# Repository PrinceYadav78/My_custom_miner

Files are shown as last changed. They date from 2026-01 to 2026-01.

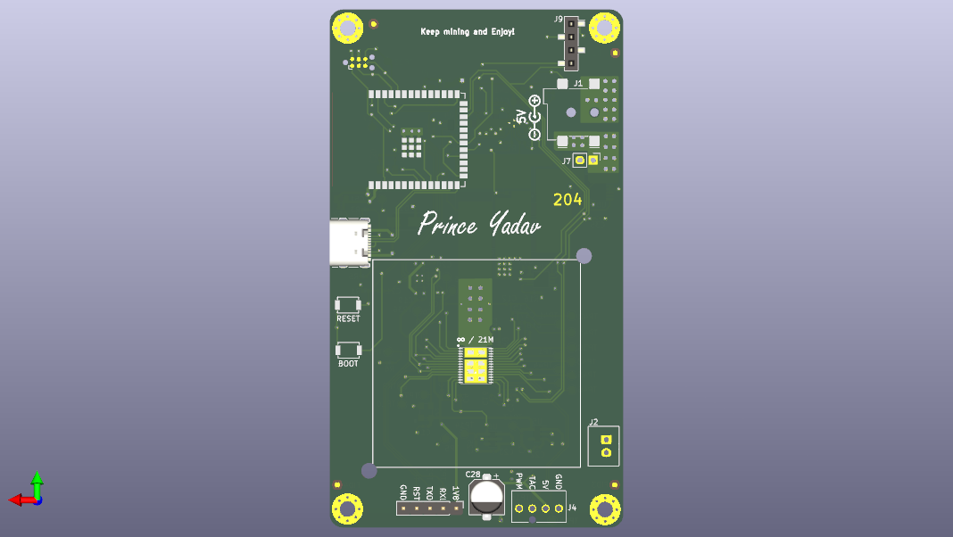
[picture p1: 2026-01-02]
img/2.png

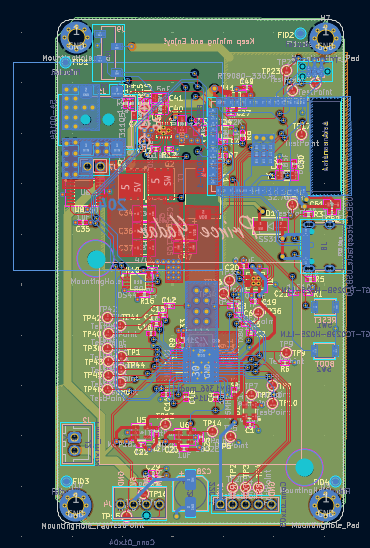
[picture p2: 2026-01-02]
img/Screenshot 2026-01-02 192543.png

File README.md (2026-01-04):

# Custom BM1366-Based Bitcoin Miner

## Overview
This project is a from-scratch design of a custom Bitcoin mining board built around the BM1366 ASIC.
The goal of this project was not to build a commercial miner, but to deeply understand how real mining
hardware is designed at the schematic and PCB level, including power delivery, grounding, routing,
and thermal considerations.

This is an educational hardware project focused on:
- High-current power delivery design
- Complex ASIC pinout handling
- Multi-rail voltage regulation
- PCB layout for power and thermal performance

## What This Board Does
- Provides regulated power rails required by the BM1366 ASIC
- Interfaces with the ASIC using SPI/control signals
- Routes extremely high current safely to the mining chip
- Is designed to be actively cooled using external heatsinks/fans
- Mines bitcoin with the firmware uploaded
The focus of this project is hardware design and manufacturability.

## Why I Built This
Most hobby electronics projects use microcontrollers or SoCs with forgiving power requirements.
Mining ASICs are the opposite — they are power-hungry, intolerant to mistakes, and layout-sensitive.
I wanted to push myself beyond typical PCB projects and learn how real mining hardware is built.

## PCB Image





## Cart




## Schematics







## BOM


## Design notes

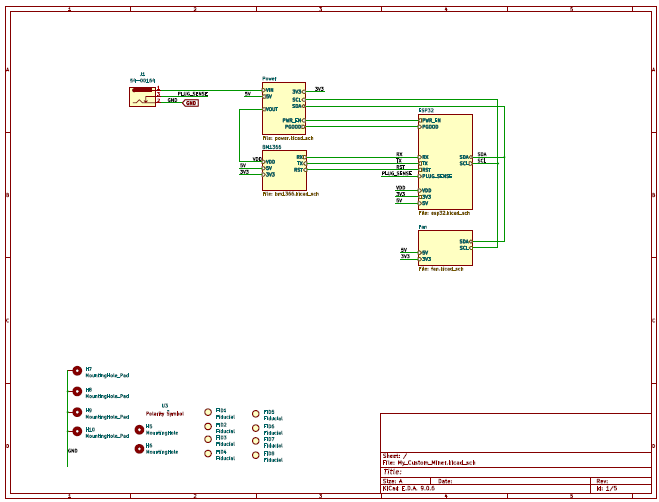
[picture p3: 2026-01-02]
img/Screenshot 2026-01-02 192621.png

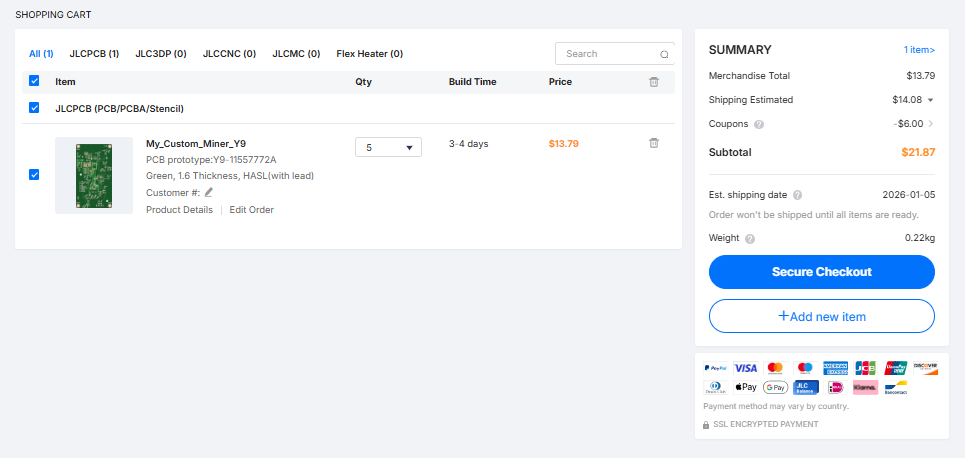
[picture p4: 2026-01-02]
img/Screenshot 2026-01-02 185541.png

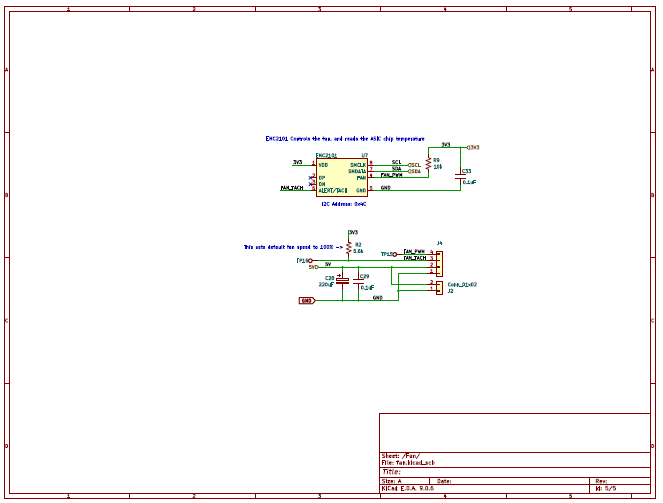
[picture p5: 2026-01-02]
img/Screenshot 2026-01-02 192647.png

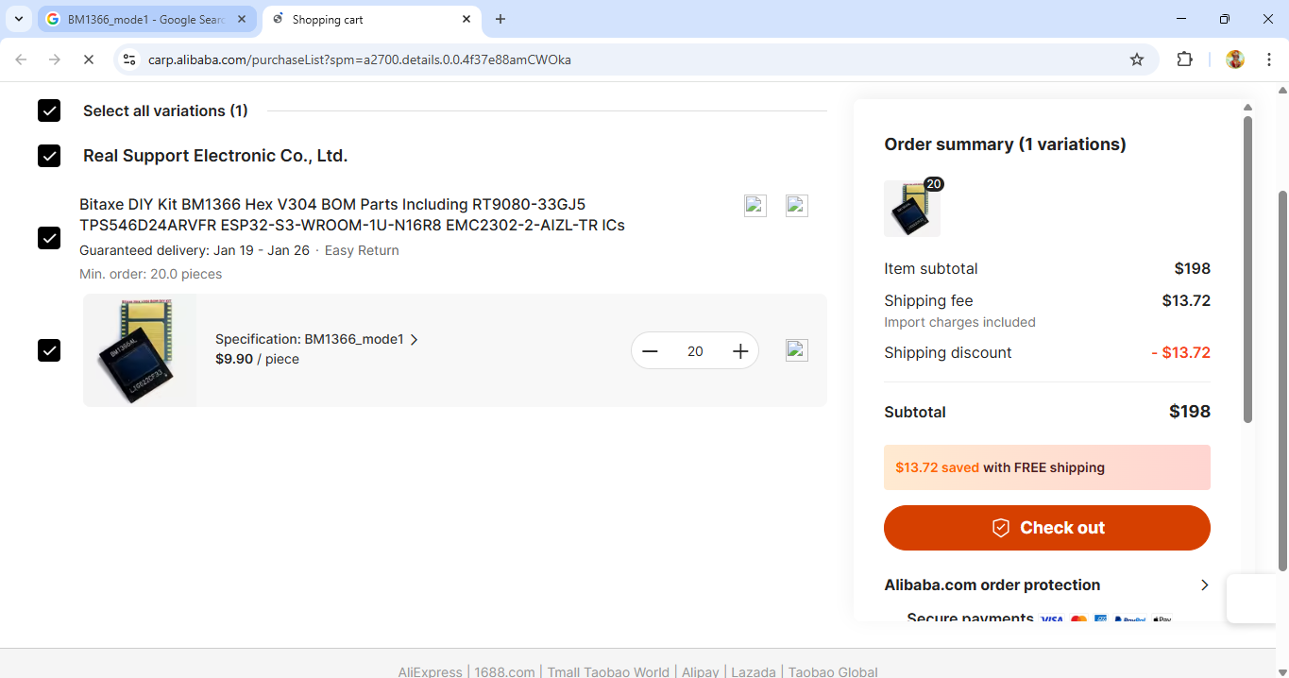
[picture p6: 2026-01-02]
img/Screenshot 2026-01-02 190240.png

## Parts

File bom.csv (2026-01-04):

Qty | Ref Des | Value | DK | PARTNO | DNP
9 | C1, C7, C9, C19, C20, C29, C33, C42, C52 | 0.1uF | 1292-1639-1-ND | 0402X104K100CT
23 | C2, C3, C4, C5, C6, C8, C10, C11, C12, C14, C15, C16, C17, C18, C21, C22, C23, C24, C25, C27, C35, C44, C49 | 1uF | 587-5514-1-ND | EMK105BJ105MV-F
1 | C13 | 330uF | 718-1028-1-ND | 293D337X9010E2TE3
1 | C28 | 220uF | 732-8422-1-ND | 865080345012
2 | C30, C31 | 6.8pF | 399-C0402C689C5GAC7867CT-ND | C0402C689C5GAC7867
3 | C34, C36, C37 | 47uF | 490-6539-1-ND | GRM32ER61C476KE15L
1 | C38 | 1uF | 1276-6471-1-ND | CL21B105KOFNNNG
1 | C39 | 3.3nF | 1276-1552-1-ND | CL05B332KB5NNNC
1 | C40 | 180pF | 311-1114-1-ND | CC0805JRNPO9BN181
1 | C41 | 1.5nF | 311-1128-1-ND | CC0805KRX7R9BB152
2 | C43, C51 | 10uF | 1276-1096-1-ND | CL21A106KOQNNNE
1 | C45 | 470pF | 1292-1580-1-ND | 0805B471K500CT
1 | C46 | 220uF | P16200CT-ND | 2R5TPE220MAFB
1 | C47 | 100uF | 445-6008-1-ND | C3216X5R0J107M160AB
1 | D1 | SS310 | SK310A-LTPMSCT-ND | SK310A-LTP
1 | J1 | 54-00164 | 839-54-00164CT-ND | 54-00164
1 | J2 | Conn_01x02 | 455-B2B-XH-A-ND | B2B-XH-A
1 | J4 | Conn_01x04 | WM4330-ND | 0470531000
1 | J8 | USB_C_Receptacle_USB2.0 | 2073-USB4105-GF-ACT-ND | USB4105-GF-A
1 | L1 | 150nH | 513-1568-1-ND | FP1005R1-R15-R
2 | Q1, Q2 | CSD17311Q5 | 296-27625-1-ND | CSD17311Q5
1 | Q4 | 2N7002K | 2N7002KWCT-ND | 2N7002KW
5 | R1, R4, R6, R7, R9 | 10k | 311-10KJRCT-ND | RC0402JR-0710KL
1 | R2 | 5.6k | 13-RC0402FR-135K6LCT-ND | RC0402FR-135K6L
2 | R3, R5 | 5.1k | RMCF0402JT5K10CT-ND | RMCF0402JT5K10
1 | R8 | 1M | 311-1.00MLRCT-ND | RC0402FR-071ML
1 | R10 | 3.83k | 311-3.83KLRCT-ND | RC0402FR-073K83L
1 | R12 | 4.12k | RMCF0402FT4K12CT-ND | RMCF0402FT4K12
1 | R13 | 1.33k | 311-1.33KLRCT-ND | RC0402FR-071K33L
1 | R14 | 4.99k | 311-4.99KLRCT-ND | RC0402FR-074K99L
1 | R15 | 3.32k | 311-3.32KLRCT-ND | RC0402FR-073K32L
1 | R16 | 80.6k | 311-80.6KLRCT-ND | RC0402FR-0780K6L
2 | SW1, SW2 | GT-TC029B-H025-L1N | 2449-CS1213AGF260CT-ND | CS1213AGF260
1 | U1 | 25MHz | 1908-O250-JO32-B-1V3-1-T1-LFCT-ND | O 25,0-JO32-B-1V3-1-T1-LF
1 | U2 | TXB0104RGYR | 296-21930-1-ND | TXB0104RGYR
1 | U5 | MCP1824T-1802E | MCP1824T-1802E/OTCT-ND | MCP1824T-1802E/OT
1 | U6 | MCP1824T-0802E | MCP1824T-0802E/OTCT-ND | MCP1824T-0802E/OT
1 | U7 | EMC2101 | EMC2101-R-ACZL-CT-ND | EMC2101-R-ACZL-TR
1 | U8 | INA260 | 296-45218-5-ND | INA260AIPW
1 | U9 | TPS40305 | 296-37445-1-ND | TPS40305DRCR
1 | U10 | DS4432U+ | DS4432U+-ND | DS4432U+
1 | U11 | RT9080-33GJ5 | 1028-1509-1-ND | RT9080-33GJ5
1 | U12 | ESP32-S3-WROOM-1 | 1965-ESP32-S3-WROOM-1-N16R8CT-ND | ESP32-S3-WROOM-1-N16R8
1 | U14 | BM1366_mode1
1 | Y1 | 32.768kHz | 728-1074-1-ND | SC32S-7PF20PPM
1 | J9 | Conn_01x04 | S5596-ND | NPTC041KFXC-RC

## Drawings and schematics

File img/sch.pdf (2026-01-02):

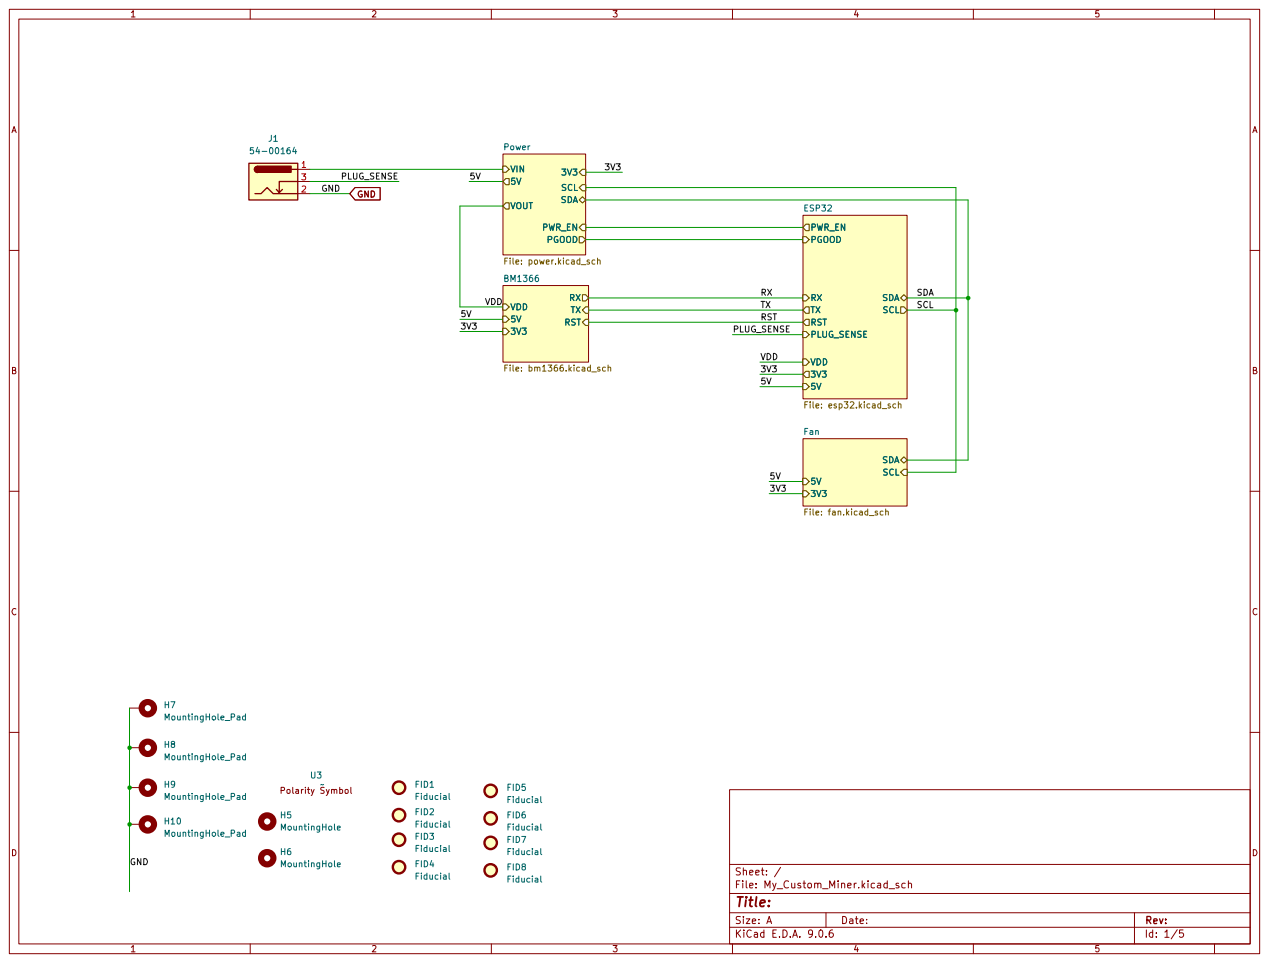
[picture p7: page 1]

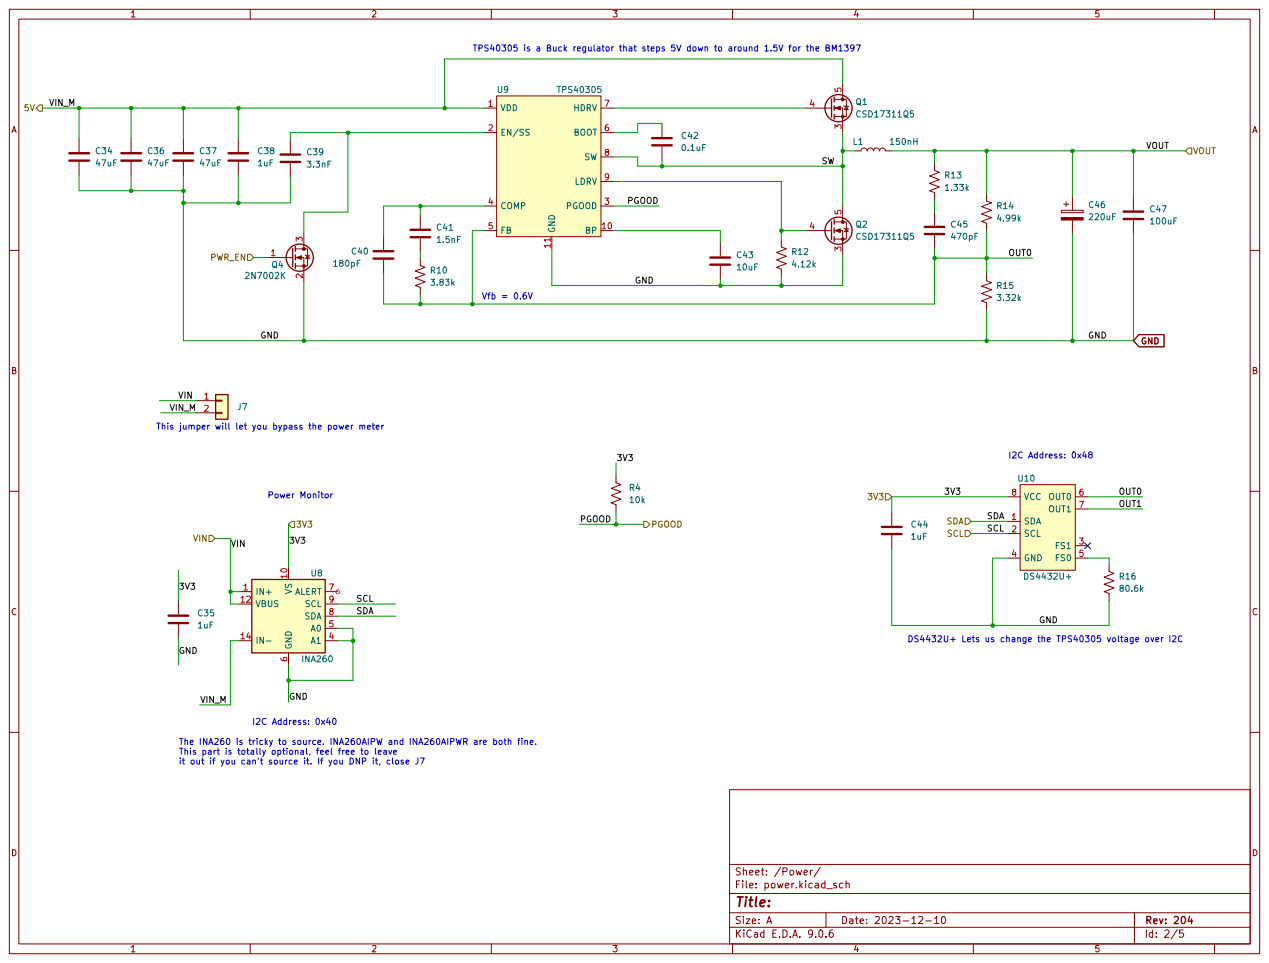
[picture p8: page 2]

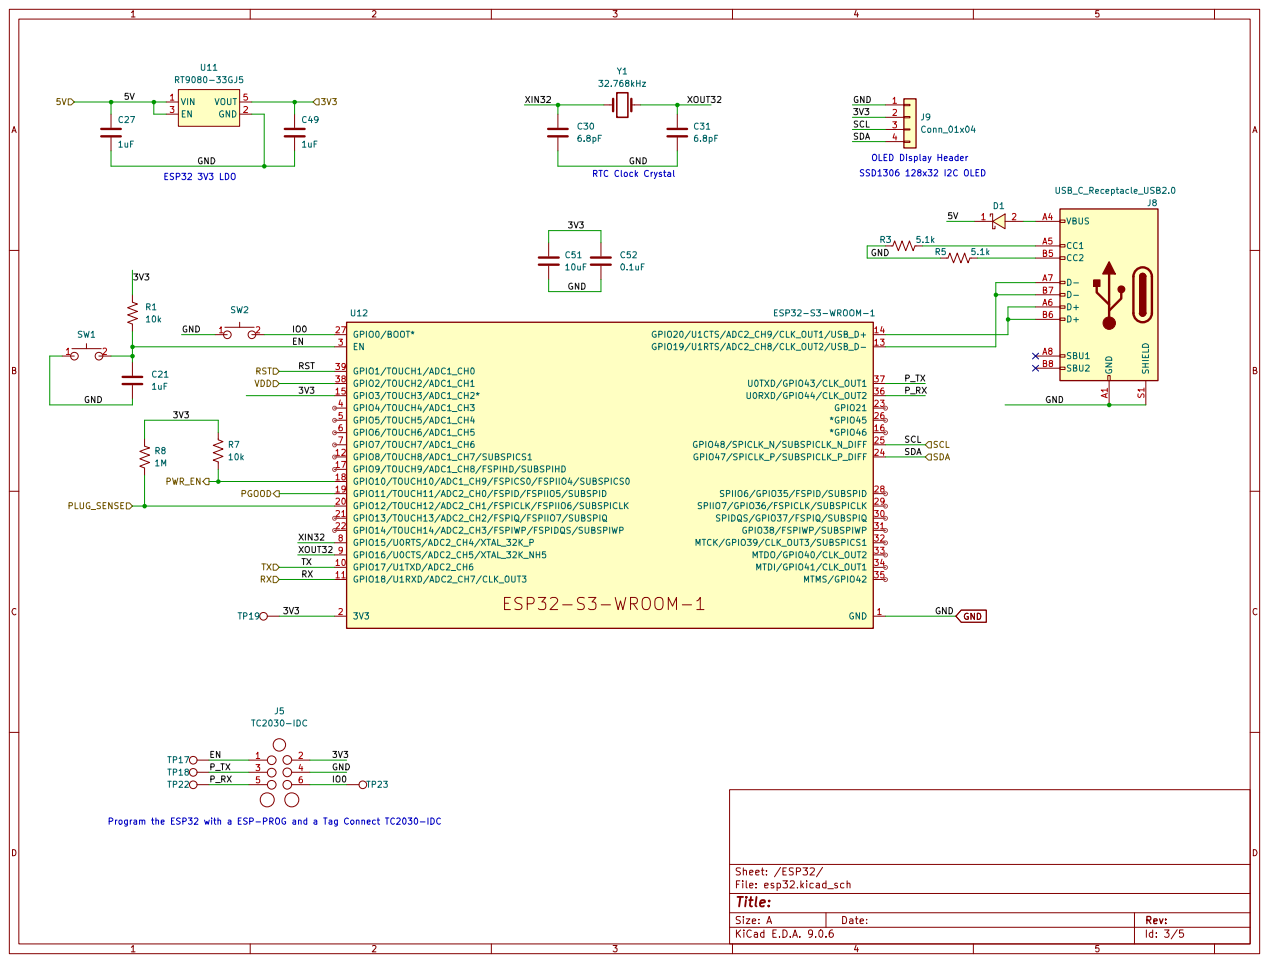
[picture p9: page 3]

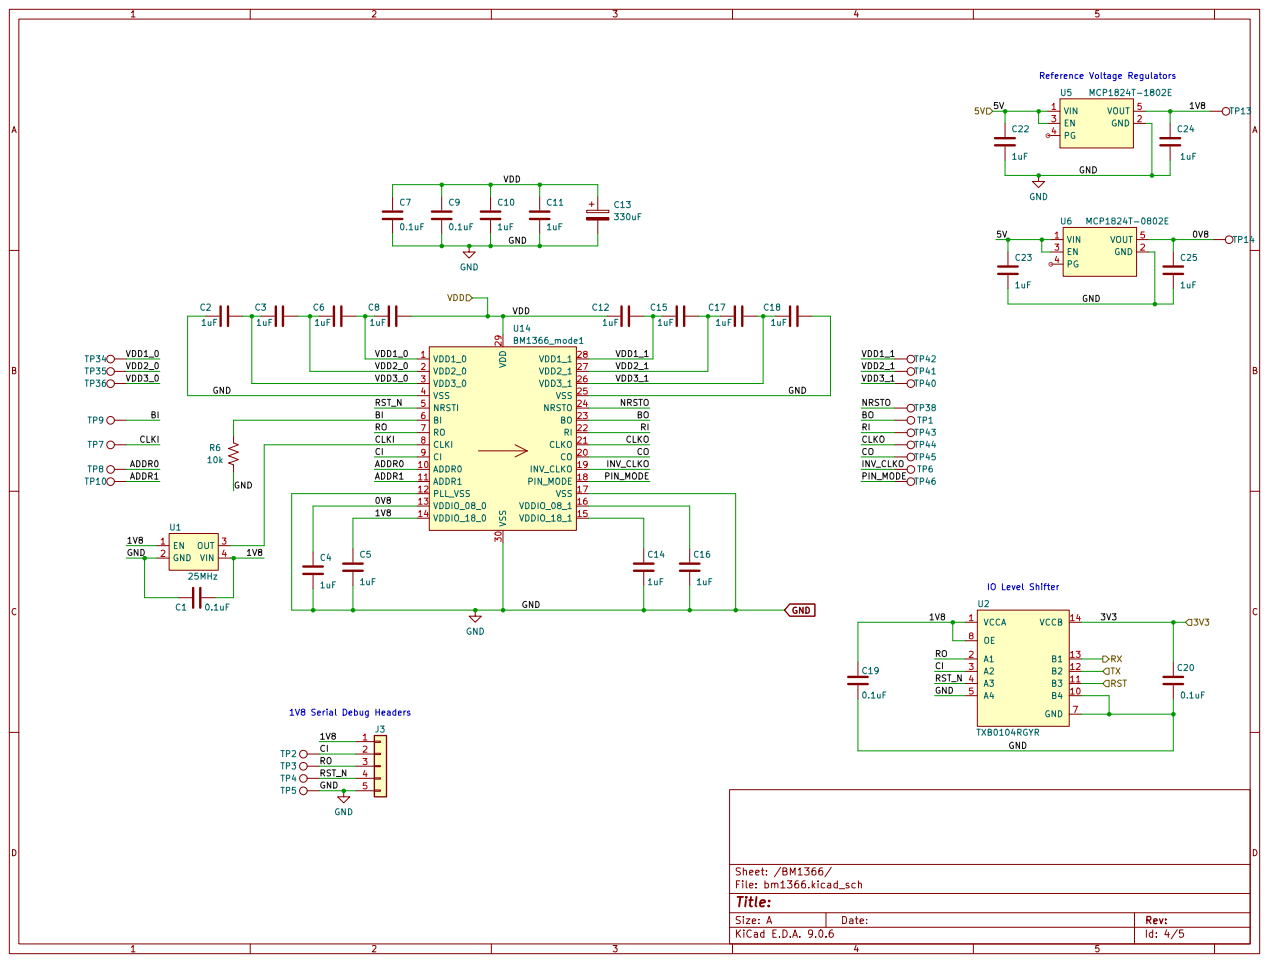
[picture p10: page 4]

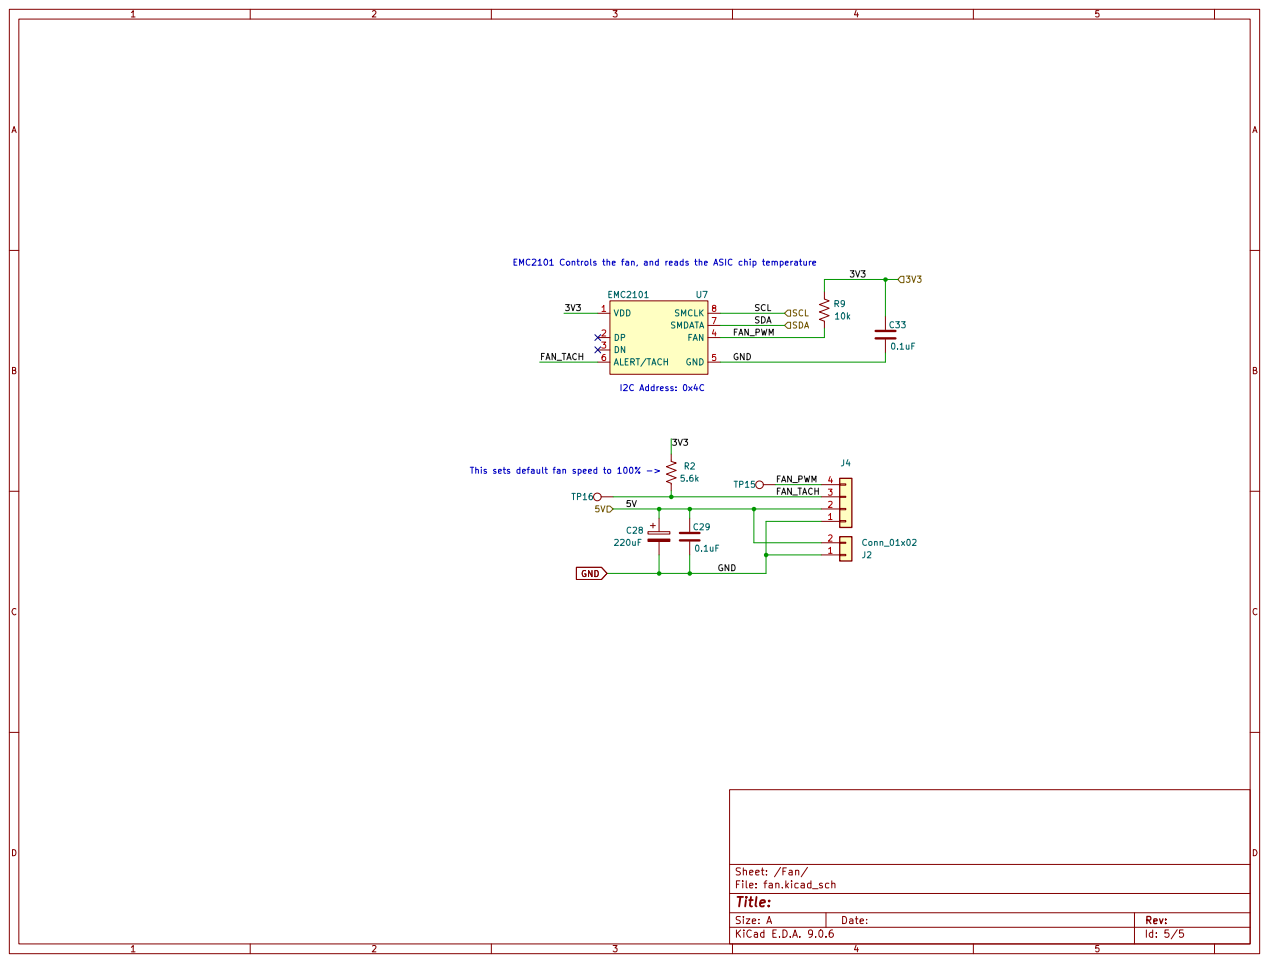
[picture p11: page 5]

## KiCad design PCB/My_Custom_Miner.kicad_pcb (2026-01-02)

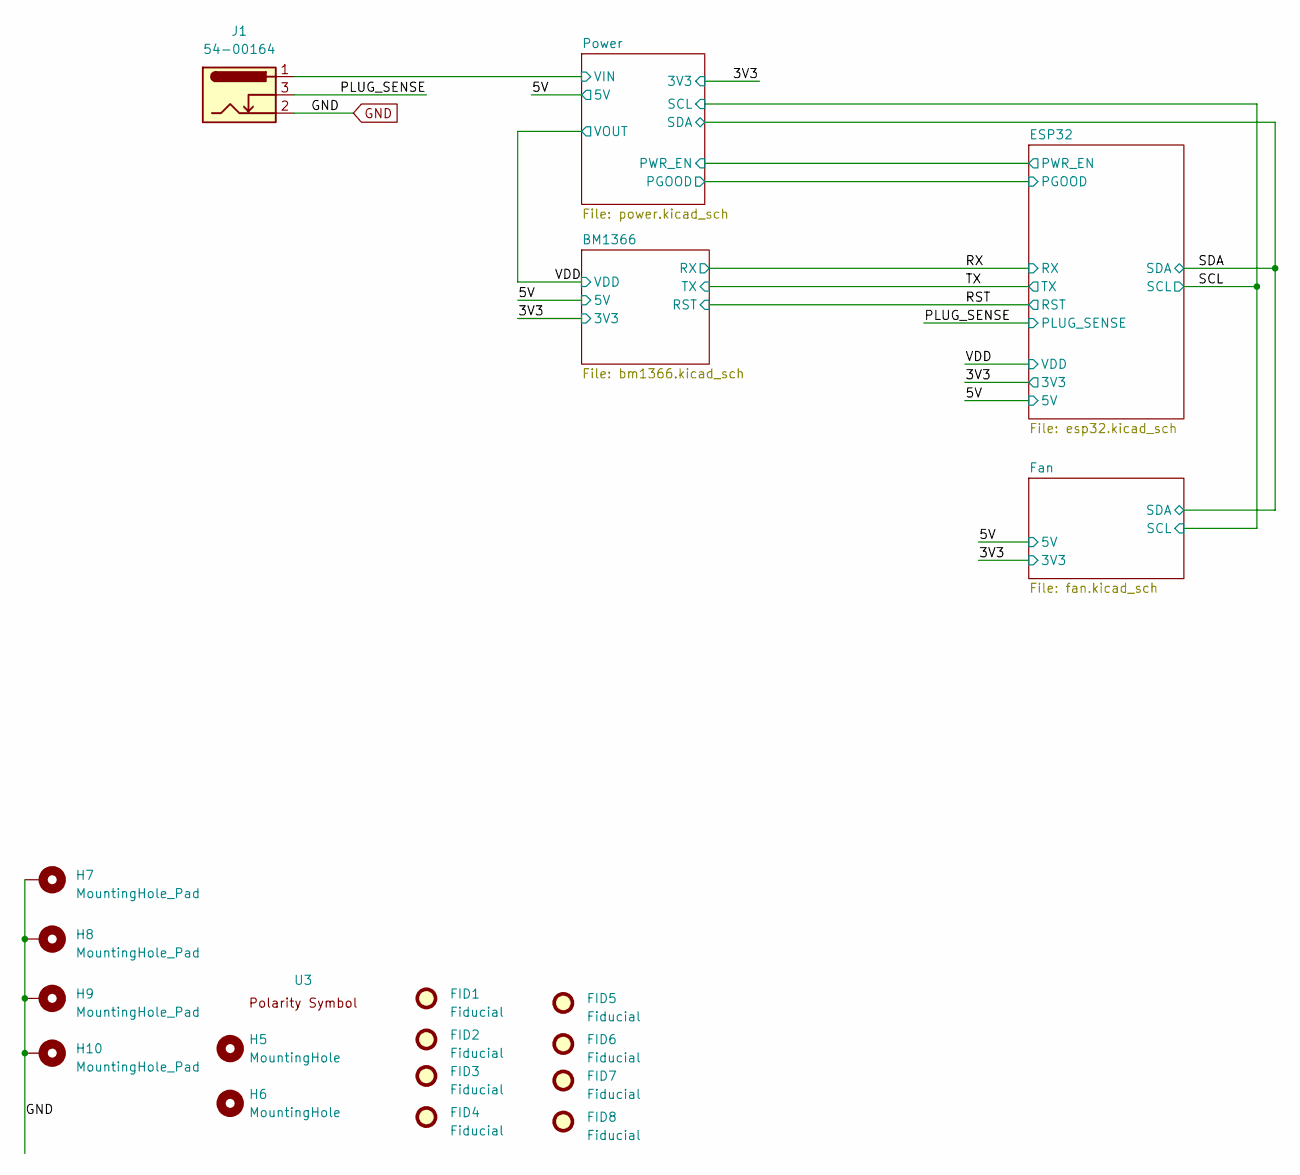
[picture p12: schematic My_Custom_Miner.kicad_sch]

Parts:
FID1, FID2, FID3, FID4, FID5, FID6, FID7, FID8: Fiducial; Fiducial_1mm_Mask2mm
H5, H6: MountingHole; MountingHole_3.5mm
H7, H8, H9, H10: MountingHole_Pad; MountingHole_3mm_Pad_Via
J1: 54-00164; BarrelJack_Wuerth_694106106102_2.0x5.5mm; PARTNO 54-00164
U3: polarity

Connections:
/PLUG_SENSE: J1.3; also elsewhere on the board
/Power/VIN: J1.1; also elsewhere on the board
GND: H7.1, H8.1, H9.1, H10.1, J1.2; also elsewhere on the board

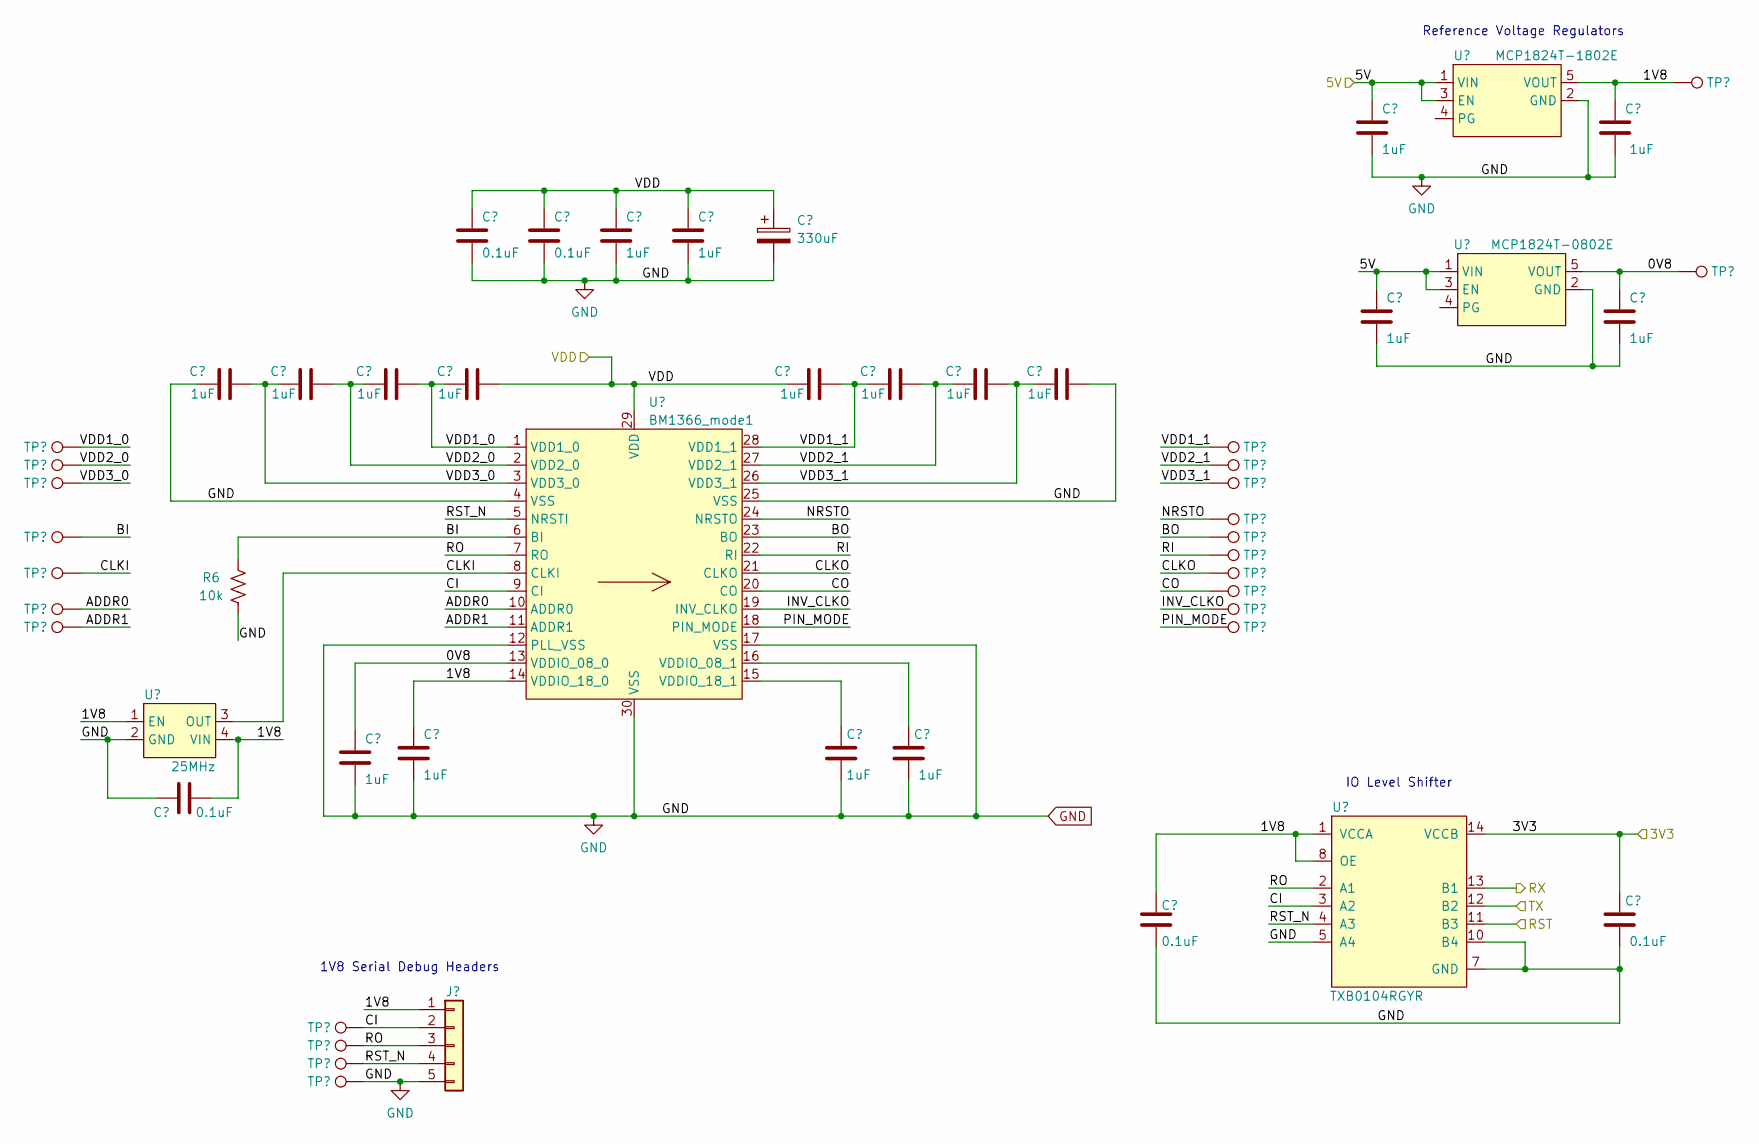
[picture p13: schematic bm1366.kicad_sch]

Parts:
C1, C7, C9, C19, C20: 0.1uF; C_0402_1005Metric; PARTNO 0402X104K100CT
C2, C3, C4, C5, C6, C8, C10, C11, C12, C14, C15, C16, C17, C18, C22, C23, C24, C25: 1uF; C_0402_1005Metric; PARTNO EMK105BJ105MV-F
C13: 330uF; CP_EIA-7343-31_Kemet-D_Pad2.25x2.55mm_HandSolder; PARTNO 293D337X9010E2TE3
J3: Conn_01x05; PinHeader_1x05_P2.54mm_Vertical
R6: 10k; R_0402_1005Metric; PARTNO RC0402JR-0710KL
TP1, TP2, TP3, TP4, TP5, TP6, TP7, TP8, TP9, TP10, TP13, TP14, TP34, TP35, TP36, TP38, TP40, TP41, TP42, TP43, TP44, TP45, TP46: TestPoint; TestPoint_Pad_D1.5mm
U1: 25MHz; O 25,0-JO32-B-1V3-1-T1-LF; PARTNO O 25,0-JO32-B-1V3-1-T1-LF
U2: TXB0104RGYR; TXB0104; PARTNO TXB0104RGYR
U5: MCP1824T-1802E; SOT-23-5; PARTNO MCP1824T-1802E/OT
U6: MCP1824T-0802E; SOT-23-5; PARTNO MCP1824T-0802E/OT
U14: BM1366_mode1; BM1366

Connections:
/3V3: C20.1, U2.14 (VCCB); also elsewhere on the board
/5V: C22.1, C23.1, U5.1 (VIN), U5.3 (EN), U6.1 (VIN), U6.3 (EN); also elsewhere on the board
/BM1366/0V8: C4.1, C25.1, TP14.1, U6.5 (VOUT), U14.13 (VDDIO_08_0)
/BM1366/1V8: C1.2, C5.1, C19.1, C24.1, J3.1, TP13.1, U1.1 (EN), U1.4 (VIN), U2.1 (VCCA), U2.8 (OE), U5.5 (VOUT), U14.14 (VDDIO_18_0)
/BM1366/ADDR0: TP8.1, U14.10 (ADDR0)
/BM1366/ADDR1: TP10.1, U14.11 (ADDR1)
/BM1366/BI: R6.2, TP9.1, U14.6 (BI)
/BM1366/BO: TP1.1, U14.23 (BO)
/BM1366/CI: J3.2, TP2.1, U2.3 (A2), U14.9 (CI)
/BM1366/CLKI: TP7.1, U1.3 (OUT), U14.8 (CLKI)
/BM1366/CLKO: TP44.1, U14.21 (CLKO)
/BM1366/CO: TP45.1, U14.20 (CO)
/BM1366/INV_CLKO: TP6.1, U14.19 (INV_CLKO)
/BM1366/NRSTO: TP38.1, U14.24 (NRSTO)
/BM1366/PIN_MODE: TP46.1, U14.18 (PIN_MODE)
/BM1366/RI: TP43.1, U14.22 (RI)
/BM1366/RO: J3.3, TP3.1, U2.2 (A1), U14.7 (RO)
/BM1366/RST_N: J3.4, TP4.1, U2.4 (A3), U14.5 (NRSTI)
/BM1366/VDD1_0: C6.2, C8.1, TP34.1, U14.1 (VDD1_0)
/BM1366/VDD1_1: C12.2, C15.1, TP42.1, U14.28 (VDD1_1)
/BM1366/VDD2_0: C3.2, C6.1, TP35.1, U14.2 (VDD2_0)
/BM1366/VDD2_1: C15.2, C17.1, TP41.1, U14.27 (VDD2_1)
/BM1366/VDD3_0: C2.2, C3.1, TP36.1, U14.3 (VDD3_0)
/BM1366/VDD3_1: C17.2, C18.1, TP40.1, U14.26 (VDD3_1)
/RST: U2.11 (B3); also elsewhere on the board
/RX: U2.13 (B1); also elsewhere on the board
/TX: U2.12 (B2); also elsewhere on the board
/VDD: C7.1, C8.2, C9.1, C10.1, C11.1, C12.1, C13.1, U14.29 (VDD); also elsewhere on the board
GND: C1.1, C2.1, C4.2, C5.2, C7.2, C9.2, C10.2, C11.2, C13.2, C14.2, C16.2, C18.2, C19.2, C20.2, C22.2, C23.2, C24.2, C25.2, J3.5, R6.1, TP5.1, U1.2 (GND), U2.5 (A4), U2.7 (GND), U2.10 (B4), U2.15 (GND), U2.16 (GND), U2.17 (GND), U2.18 (GND), U2.19 (GND), U5.2 (GND), U6.2 (GND), U14.4 (VSS), U14.12 (PLL_VSS), U14.17 (VSS), U14.25 (VSS), U14.30 (VSS); also elsewhere on the board
unnamed: C16.1, U14.16 (VDDIO_08_1)
unnamed: C14.1, U14.15 (VDDIO_18_1)

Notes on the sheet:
1V8 Serial Debug Headers
Reference Voltage Regulators
IO Level Shifter

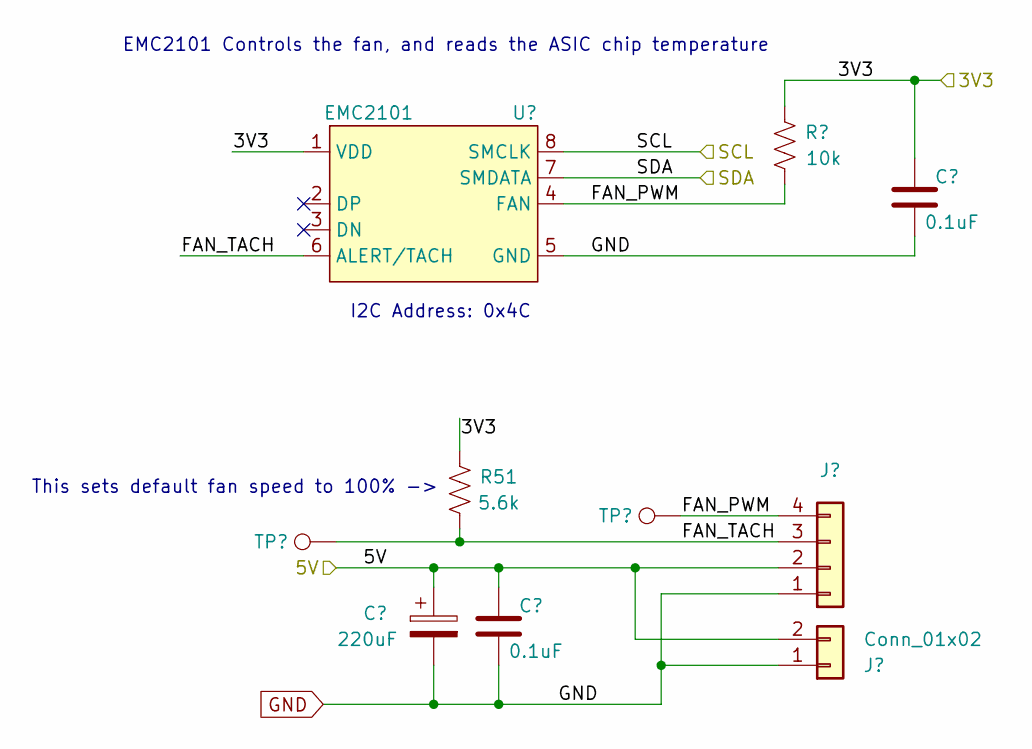
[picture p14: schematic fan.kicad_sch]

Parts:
C28: 220uF; CP_Elec_6.3x7.7; PARTNO 865080345012
C29, C33: 0.1uF; C_0402_1005Metric; PARTNO 0402X104K100CT
J2: Conn_01x02; JST_XH_B2B-XH-A_1x02_P2.50mm_Vertical; PARTNO B2B-XH-A
J4: Conn_01x04; 470531000; PARTNO 0470531000
R9: 10k; R_0402_1005Metric; PARTNO RC0402JR-0710KL
R51: 5.6k; R_0402_1005Metric; PARTNO RC0402FR-135K6L
TP15, TP16: TestPoint; TestPoint_Pad_D1.5mm
U7: EMC2101; TSSOP-8_3x3mm_P0.65mm; PARTNO EMC2101-R-ACZL-TR

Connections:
/3V3: C33.1, R9.2, U7.1 (VDD); also elsewhere on the board
/5V: C28.1, C29.1, J2.2, J4.2; also elsewhere on the board
/Fan/FAN_PWM: J4.4, R9.1, TP15.1, U7.4 (FAN)
/Fan/FAN_TACH: J4.3, TP16.1, U7.6 (ALERT/TACH); also elsewhere on the board
/SCL: U7.8 (SMCLK); also elsewhere on the board
/SDA: U7.7 (SMDATA); also elsewhere on the board
GND: C28.2, C29.2, C33.2, J2.1, J4.1, U7.5 (GND); also elsewhere on the board

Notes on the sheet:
EMC2101 Controls the fan, and reads the ASIC chip temperature
This sets default fan speed to 100% ->
I2C Address: 0x4C

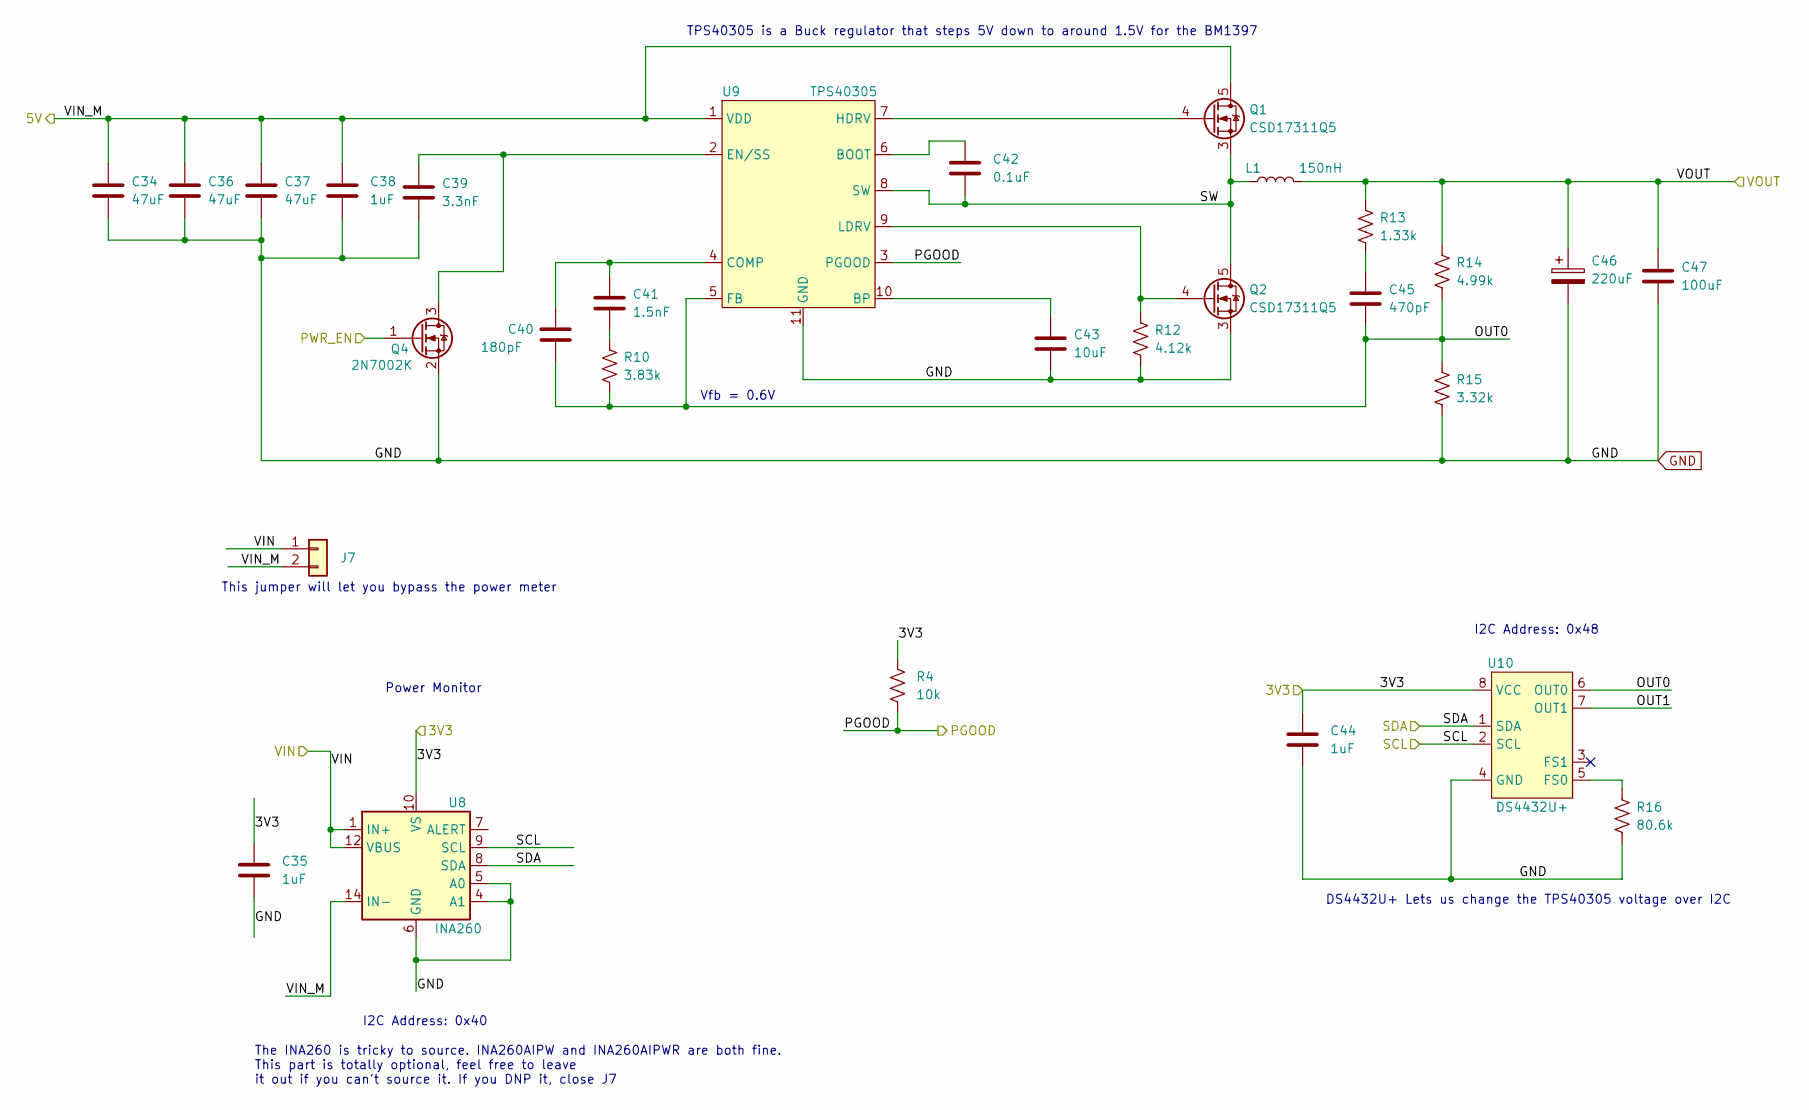
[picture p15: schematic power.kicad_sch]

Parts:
C34, C36, C37: 47uF; C_1210_3225Metric; PARTNO GRM32ER61C476KE15L
C35, C44: 1uF; C_0402_1005Metric; PARTNO EMK105BJ105MV-F
C38: 1uF; C_0805_2012Metric; PARTNO CL21B105KOFNNNG
C39: 3.3nF; C_0402_1005Metric; PARTNO CL05B332KB5NNNC
C40: 180pF; C_0805_2012Metric; PARTNO CC0805JRNPO9BN181
C41: 1.5nF; C_0805_2012Metric; PARTNO CC0805KRX7R9BB152
C42: 0.1uF; C_0402_1005Metric; PARTNO 0402X104K100CT
C43: 10uF; C_0805_2012Metric; PARTNO CL21A106KOQNNNE
C45: 470pF; C_0805_2012Metric; PARTNO 0805B471K500CT
C46: 220uF; CAP_2R5TPE220MAFB; PARTNO 2R5TPE220MAFB
C47: 100uF; C_1206_3216Metric; PARTNO C3216X5R0J107M160AB
J7: Conn_01x02; PinHeader_1x02_P2.54mm_Vertical
L1: 150nH; FP1005R1-R15-R; PARTNO FP1005R1-R15-R
Q1, Q2: CSD17311Q5; PARTNO CSD17311Q5
Q4: 2N7002K; SOT-323_SC-70; PARTNO 2N7002KW
R4: 10k; R_0402_1005Metric; PARTNO RC0402JR-0710KL
R10: 3.83k; R_0402_1005Metric; PARTNO RC0402FR-073K83L
R12: 4.12k; R_0402_1005Metric; PARTNO RMCF0402FT4K12
R13: 1.33k; R_0402_1005Metric; PARTNO RC0402FR-071K33L
R14: 4.99k; R_0402_1005Metric; PARTNO RC0402FR-074K99L
R15: 3.32k; R_0402_1005Metric; PARTNO RC0402FR-073K32L
R16: 80.6k; R_0402_1005Metric; PARTNO RC0402FR-0780K6L
U8: INA260; TSSOP-16_4.4x5mm_P0.65mm; PARTNO INA260AIPW
U9: TPS40305; PARTNO TPS40305DRCR
U10: DS4432U+; TSSOP-8_3x3mm_P0.65mm; PARTNO DS4432U+

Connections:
/3V3: C35.1, C44.1, R4.1, U8.10 (VS), U10.8 (VCC); also elsewhere on the board
/5V: C34.1, C36.1, C37.1, C38.1, J7.2, Q1.5 (D), U8.14 (IN-), U8.15 (IN-), U8.16 (IN-), U9.1 (VDD); also elsewhere on the board
/ESP32/PWR_EN: Q4.1 (G); also elsewhere on the board
/Power/OUT0: C40.2, C45.2, R10.2, R14.2, R15.1, U9.5 (FB), U10.6 (OUT0)
/Power/OUT1: U10.7 (OUT1)
/Power/PGOOD: R4.2, U9.3 (PGOOD); also elsewhere on the board
/Power/SW: C42.2, L1.1, Q1.1, Q1.2, Q1.3 (S), Q2.5 (D), U9.8 (SW)
/Power/VIN: J7.1, U8.1 (IN+), U8.2 (IN+), U8.3 (IN+), U8.12 (VBUS); also elsewhere on the board
/SCL: U8.9 (SCL), U10.2 (SCL); also elsewhere on the board
/SDA: U8.8 (SDA), U10.1 (SDA); also elsewhere on the board
/VDD: C46.1, C47.1, L1.2, R13.1, R14.1; also elsewhere on the board
GND: C34.2, C35.2, C36.2, C37.2, C38.2, C39.2, C43.2, C44.2, C46.2, C47.2, Q2.1, Q2.2, Q2.3 (S), Q4.2 (S), R12.2, R15.2, R16.2, U8.4 (A1), U8.5 (A0), U8.6 (GND), U8.11 (GND), U9.11 (GND), U10.4 (GND); also elsewhere on the board
unnamed: C41.2, R10.1
unnamed: C45.1, R13.2
unnamed: Q1.4 (G), U9.7 (HDRV)
unnamed: Q2.4 (G), R12.1, U9.9 (LDRV)
unnamed: C39.1, Q4.3 (D), U9.2 (EN/SS)
unnamed: C42.1, U9.6 (BOOT)
unnamed: C43.1, U9.10 (BP)
unnamed: C40.1, C41.1, U9.4 (COMP)
unnamed: R16.1, U10.5 (FS0)

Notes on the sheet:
DS4432U+ Lets us change the TPS40305 voltage over I2C
I2C Address: 0x48
The INA260 is tricky to source. INA260AIPW and INA260AIPWR are both fine. This part is totally optional, feel free to leave it out if you can't source it. If you DNP it, close J7
Power Monitor
TPS40305 is a Buck regulator that steps 5V down to around 1.5V for the BM1397
I2C Address: 0x40
Vfb = 0.6V
This jumper will let you bypass the power meter

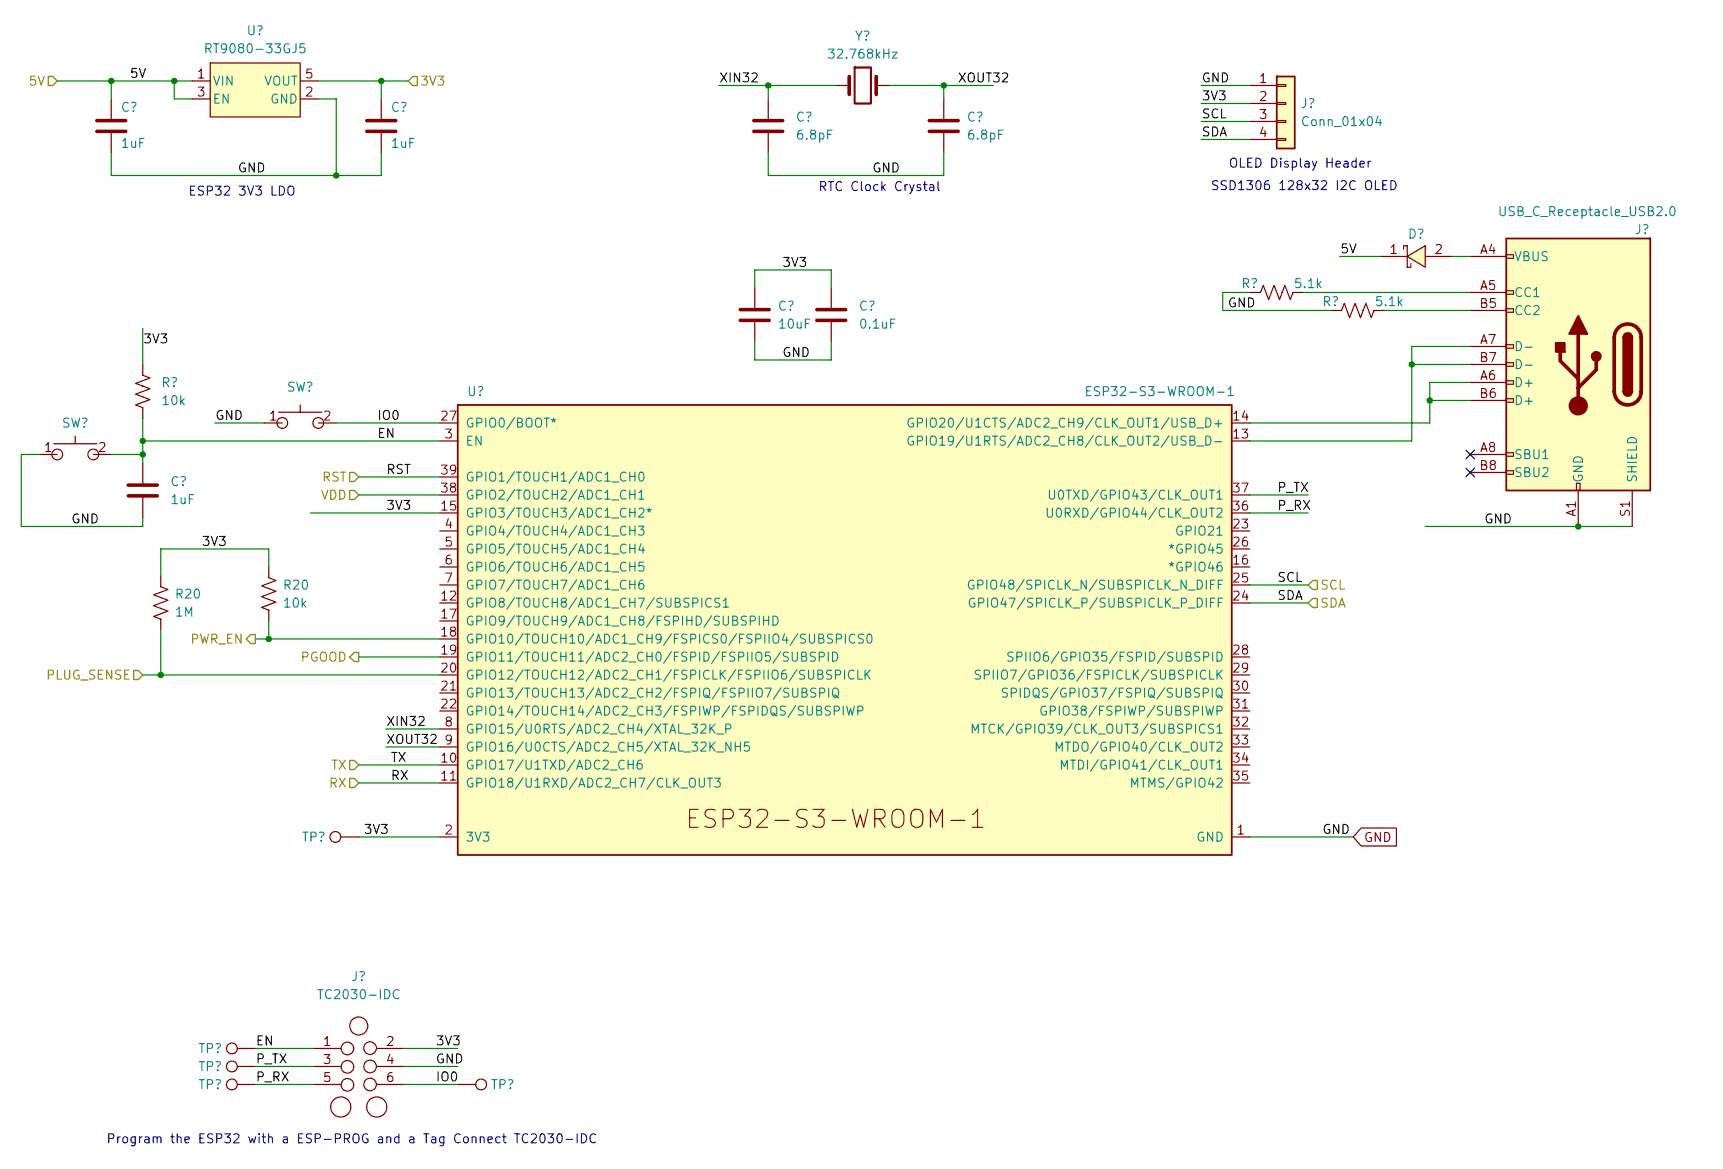
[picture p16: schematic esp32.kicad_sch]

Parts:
C21, C27, C49: 1uF; C_0402_1005Metric; PARTNO EMK105BJ105MV-F
C30, C31: 6.8pF; C_0402_1005Metric; PARTNO C0402C689C5GAC7867
C51: 10uF; C_0805_2012Metric; PARTNO CL21A106KOQNNNE
C52: 0.1uF; C_0402_1005Metric; PARTNO 0402X104K100CT
D1: SS310; D_SMA; PARTNO SK310A-LTP
J5: TC2030-IDC; Tag-Connect_TC2030-IDC-NL_2x03_P1.27mm_Vertical
J8: USB_C_Receptacle_USB2.0; USB_C_Receptacle_GCT_USB4105-xx-A_16P_TopMnt_Horizontal; PARTNO USB4105-GF-A
J9: Conn_01x04; PinSocket_1x04_P2.54mm_Vertical_SMD_Pin1Right; PARTNO NPTC041KFXC-RC
R1: 10k; R_0402_1005Metric; PARTNO RC0402JR-0710KL
R3, R5: 5.1k; R_0402_1005Metric; PARTNO RMCF0402JT5K10
R20: 1M; R_0402_1005Metric; PARTNO RC0402FR-071ML
SW1, SW2: GT-TC029B-H025-L1N; SW_CS1213AGF260_CRS; PARTNO CS1213AGF260
TP17, TP18, TP19, TP22, TP23: TestPoint; TestPoint_Pad_D1.5mm
U11: RT9080-33GJ5; PARTNO RT9080-33GJ5
U12: ESP32-S3-WROOM-1; PARTNO ESP32-S3-WROOM-1-N16R8
Y1: 32.768kHz; SC32S-7PF20PPM; PARTNO SC32S-7PF20PPM

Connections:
/3V3: C49.1, C51.1, C52.1, J5.2, J9.2, R1.1, TP19.1, U11.5 (VOUT), U12.2 (3V3), U12.15 (GPIO3/TOUCH3/ADC1_CH2*); also elsewhere on the board
/5V: C27.1, D1.1, U11.1 (VIN), U11.3 (EN); also elsewhere on the board
/ESP32/EN: C21.1, J5.1, R1.2, SW1.2, TP17.1, U12.3 (EN)
/ESP32/IO0: J5.6, SW2.2, TP23.1, U12.27 (GPIO0/BOOT*)
/ESP32/PWR_EN: U12.18 (GPIO10/TOUCH10/ADC1_CH9/FSPICS0/FSPIIO4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); also elsewhere on the board
/ESP32/P_RX: J5.5, TP22.1, U12.36 (U0RXD/GPIO44/CLK_OUT2)
/ESP32/P_TX: J5.3, TP18.1, U12.37 (U0TXD/GPIO43/CLK_OUT1)
/ESP32/XIN32: C30.1, U12.8 (GPIO15/U0RTS/ADC2_CH4/XTAL_32K_P), Y1.1
/ESP32/XOUT32: C31.1, U12.9 (GPIO16/U0CTS/ADC2_CH5/XTAL_32K_NH5), Y1.2
/PLUG_SENSE: U12.20 (GPIO12/TOUCH12/ADC2_CH1/FSPICLK/FSPIIO6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); also elsewhere on the board
/Power/PGOOD: U12.19 (GPIO11/TOUCH11/ADC2_CH0/FSPID/FSPIIO5/S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); also elsewhere on the board
/RST: U12.39 (GPIO1/TOUCH1/ADC1_CH0); also elsewhere on the board
/RX: U12.11 (GPIO18/U1RXD/ADC2_CH7/CLK_OUT3); also elsewhere on the board
/SCL: J9.3, U12.25 (GPIO48/SPICLK_N/SUBSPICLK_N_DIFF); also elsewhere on the board
/SDA: J9.4, U12.24 (GPIO47/SPICLK_P/SUBSPICLK_P_DIFF); also elsewhere on the board
/TX: U12.10 (GPIO17/U1TXD/ADC2_CH6); also elsewhere on the board
/VDD: U12.38 (GPIO2/TOUCH2/ADC1_CH1); also elsewhere on the board
GND: C21.2, C27.2, C30.2, C31.2, C49.2, C51.2, C52.2, J5.4, J8.A1 (GND), J8.A12 (GND), J8.B1 (GND), J8.B12 (GND), J8.S1 (SHIELD), J9.1, R3.1, R5.1, SW1.1, SW2.1, U11.2 (GND), U12.1 (GND), U12.40 (GND), U12.41 (GND); also elsewhere on the board
unnamed: D1.2, J8.A4 (VBUS), J8.A9 (VBUS), J8.B4 (VBUS), J8.B9 (VBUS)
unnamed: J8.A5 (CC1), R3.2
unnamed: J8.B5 (CC2), R5.2
unnamed: J8.A7 (D-), J8.B7 (D-), U12.13 (GPIO19/U1RTS/ADC2_CH8/CLK_OUT2/USB_D-)
unnamed: J8.A6 (D+), J8.B6 (D+), U12.14 (GPIO20/U1CTS/ADC2_CH9/CLK_OUT1/USB_D+)

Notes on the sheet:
RTC Clock Crystal
ESP32 3V3 LDO
Program the ESP32 with a ESP-PROG and a Tag Connect TC2030-IDC
SSD1306 128x32 I2C OLED
OLED Display Header

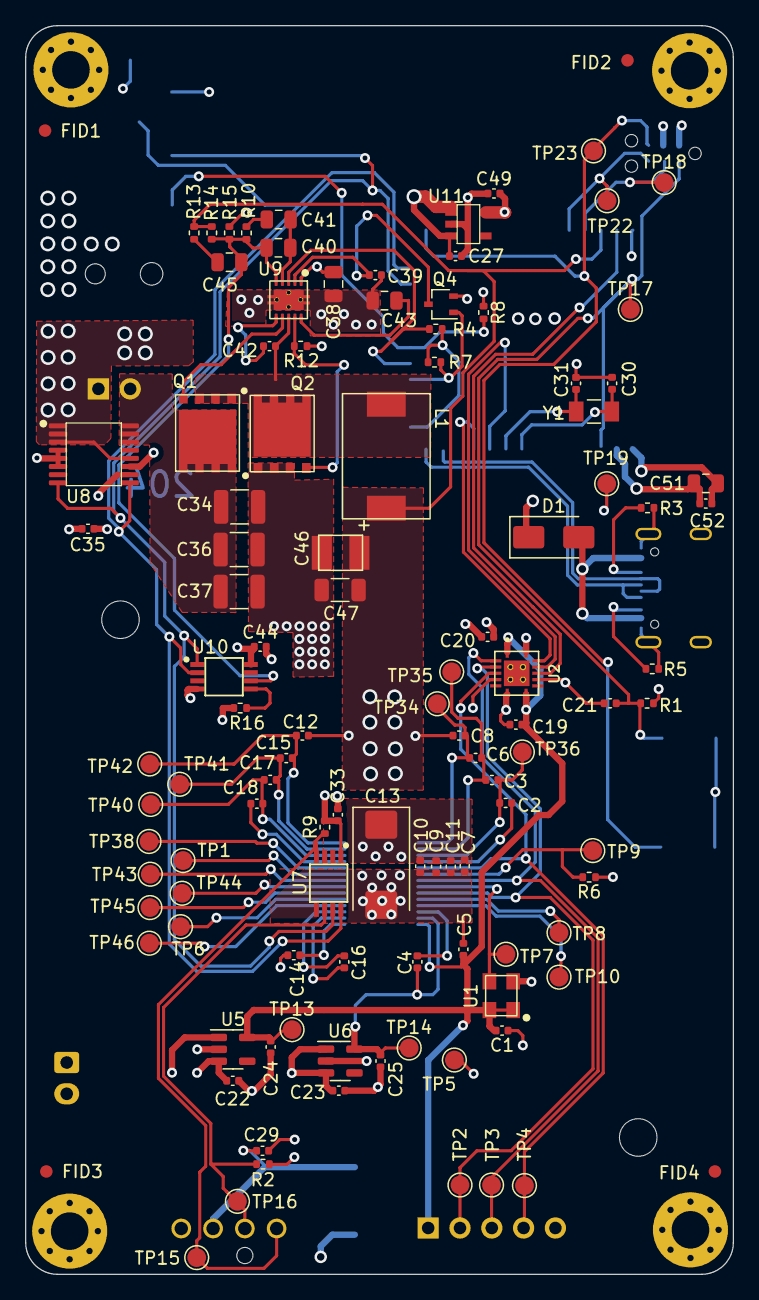
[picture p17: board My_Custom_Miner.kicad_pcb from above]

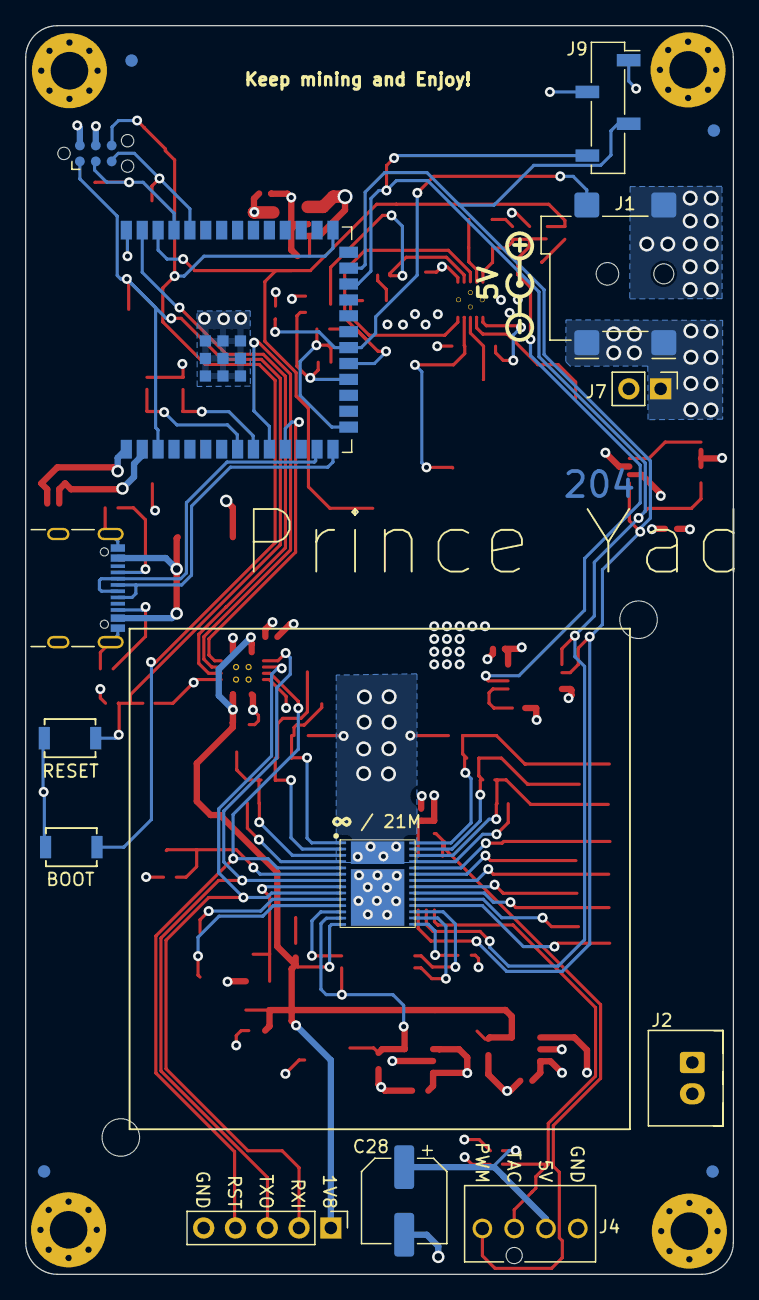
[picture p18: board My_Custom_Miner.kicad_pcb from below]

Board: 4 copper layers, 56.5 x 99.8 mm, 135 parts (18 on the bottom side), 61 nets.

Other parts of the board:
R2: 5.6k; R_0402_1005Metric
R7: 10k; R_0402_1005Metric
R8: 1M; R_0402_1005Metric

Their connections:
/3V3: R2.2, R7.1, R8.1; also elsewhere on the board
/ESP32/PWR_EN: R7.2; also elsewhere on the board
/Fan/FAN_TACH: R2.1; also elsewhere on the board
/PLUG_SENSE: R8.2; also elsewhere on the board
